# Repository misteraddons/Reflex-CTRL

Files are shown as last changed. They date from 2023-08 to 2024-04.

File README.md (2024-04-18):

# General
A series of drop in replacement circuit boards to convert console controllers directly to USB. Reflex CTRL uses [GP2040-CE](https://gp2040-ce.info/#/) firmware, and boasts an incredibly low 0.8ms latency.

## Controllers

### Config
`Web Config` mode = Start + Plug in USB, then visit [192.168.7.1](192.168.7.1)

### CTRL NES
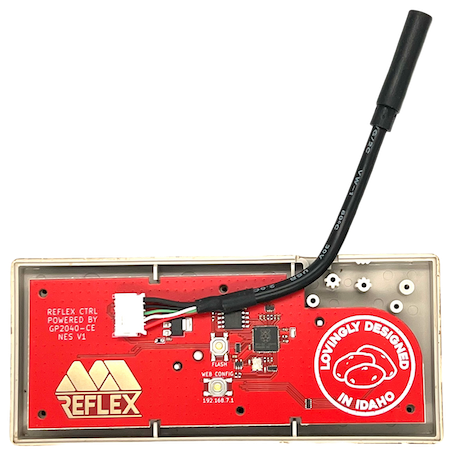
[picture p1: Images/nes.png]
CTRL NES


Update Firmware: Select + Start + Up + Plug in USB
| Mode | Button Combo |
| --- | --- |
| Nintendo Switch Mode | B + Plug in USB |
| Xinput | A + Plug in USB |

| Shortcut | Button Combo |
| --- | --- |
| D-pad mode | Select + Start + Down |
| Left analog stick mode | Select + Start + Left |
| Right analog stick mode | Select + Start + Right |
| Home | Select + Start + Up |

### CTRL SNES
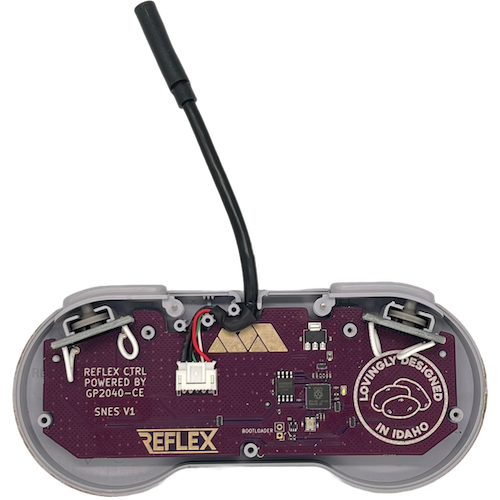
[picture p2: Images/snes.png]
CTRL SNES


Update Firmware: Select + Start + Up + Plug in USB
| Mode | Button Combo |
| --- | --- |
| Nintendo Switch Mode | B + Plug in USB |
| Xinput | A + Plug in USB |
| DirectInput / PS3 | Y + Plug in USB |
| PS4 | X + Plug in USB* |
* PS4 mode requires additional steps. Enter `Web Config` mode, then go to `Settings` >  `Input Mode Settings` > `PS4` > `Authentication Mode Settings` for more info.

| Shortcut | Button Combo |
| --- | --- |
| D-pad mode | Select + Start + Down |
| Left analog stick mode | Select + Start + Left |
| Right analog stick mode | Select + Start + Right |
| Home | Select + Start + Up |
| Turbo enable/disable | Left + Select + Button |
| Turbo rate increase | Left + Up + Select |
| Turbo rate decrease | Left + Down + Select |

### CTRL Virtual Boy
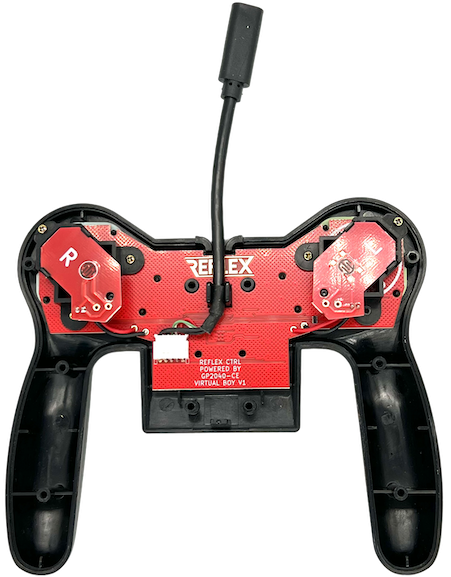
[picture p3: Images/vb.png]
CTRL Virtual Boy


Update Firmware: Select + Start + Up + Plug in USB
| Mode | Button Combo |
| --- | --- |
| Nintendo Switch Mode | Right DPad Down + Plug in USB |
| Xinput | Right DPad Right + Plug in USB |
| DirectInput / PS3 | Right DPad Left + Plug in USB |
| PS4 | Right DPad Up + Plug in USB* |
| Keyboard | R + Plug in USB* |
* PS4 mode requires additional steps. Enter `Web Config` mode, then go to `Settings` >  `Input Mode Settings` > `PS4` > `Authentication Mode Settings` for more info.

| Shortcut | Button Combo |
| --- | --- |
| D-pad mode | Select + Start + Down |
| Left analog stick mode | Select + Start + Left |
| Right analog stick mode | Select + Start + Right |
| Home | Select + Start + Up |

### CTRL Genesis 6
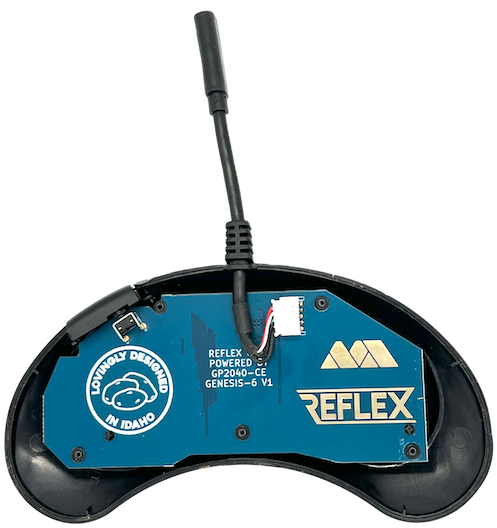
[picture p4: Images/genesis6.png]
CTRL Genesis 6


Update Firmware: Mode + Start + Up + Plug in USB
| Mode | Button Combo |
| --- | --- |
| Nintendo Switch Mode | A + Plug in USB |
| Xinput | B + Plug in USB |
| DirectInput / PS3 | X + Plug in USB |
| PS4 | Y + Plug in USB* |
* PS4 mode requires additional steps. Enter `Web Config` mode, then go to `Settings` >  `Input Mode Settings` > `PS4` > `Authentication Mode Settings` for more info.

| Shortcut | Button Combo |
| --- | --- |
| D-pad mode | Mode + Start + Down |
| Left analog stick mode | Mode + Start + Left |
| Right analog stick mode | Mode + Start + Right |
| Home | Mode + Start + Up |

### CTRL Saturn
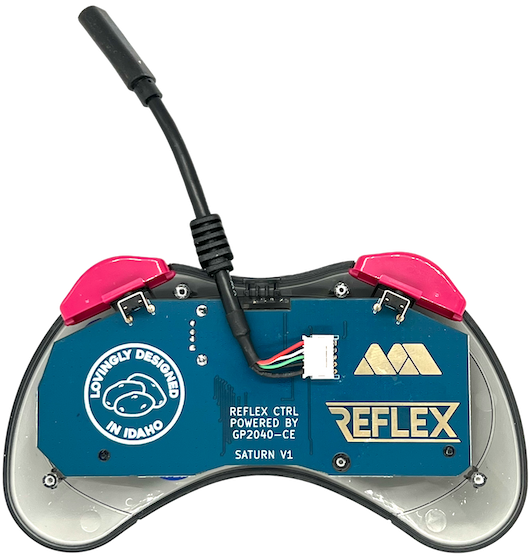
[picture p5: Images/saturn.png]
CTRL Saturn


Update Firmware: Start + Plug in USB to enter `Web Config`. Navigate to 192.168.7.1. Click `Reboot`, then `USB (BOOT SEL)`.
| Mode | Button Combo |
| --- | --- |
| Nintendo Switch Mode | A + Plug in USB |
| Xinput | B + Plug in USB |
| DirectInput / PS3 | X + Plug in USB |
| PS5 | Y + Plug in USB (Requires authentication dongle) |
* PS4 mode requires additional steps. Enter `Web Config` mode, then go to `Settings` >  `Input Mode Settings` > `PS4` > `Authentication Mode Settings` for more info.
* Xbox authentication requires an authentication dongle (TBD)

| Shortcut | Button Combo |
| --- | --- |
| D-pad mode | L + Start + Down |
| Left analog stick mode | L + Start + Left |
| Right analog stick mode | L + Start + Right |
| Home | L + Start + Up |

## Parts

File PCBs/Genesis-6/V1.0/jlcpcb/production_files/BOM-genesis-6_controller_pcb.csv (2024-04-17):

Comment | Designator | Footprint | LCSC
Conn_01x05 | J5 | JST_PH_S5B-PH-K_1x05_P2.00mm_Horizontal | C10402
1K | R3,R5,R8 | R_0402_1005Metric | C11702
SCHOTTKY DIODE | D1 | D_0603_1608Metric | C143772
100n | C11,C12,C13,C14,C5,C6,C7,C9 | C_0402_1005Metric | C1525
10u | C1,C2 | C_0402_1005Metric | C15525
27p | C3,C4 | C_0402_1005Metric | C1557
RP2040 | U4 | RP2040-QFN-56 | C2040
LED | D2 | LED_0603_1608Metric | C2290
27 | R6,R7 | R_0402_1005Metric | C25100
10K | R4 | R_0402_1005Metric | C25744
W25Q16 | FLASH1 | RPI_SPI_Flash_Universal_W25Q16 | C2843335
TVS_RCLAMP0524P-N | U1,U2,U5,U6,U7 | UDFN-10_1.35x2.6mm_P0.5mm | C316044
SW_Push | SW13,SW5 | SW_SPST_SKQG_WithStem | C318884
Button_Pad | SW12 | SW_Tactile_SPST_Angled_PTS645Vx39-2LFS | C455127
1u | C10,C8 | C_0402_1005Metric | C52923
AMS1117-3.3 | U3 | SOT-223-3_TabPin2 | C6186
Crystal_GND24_Small | Y1 | Crystal_SMD_SeikoEpson_TSX3225-4Pin_3.2x2.5mm | C9002

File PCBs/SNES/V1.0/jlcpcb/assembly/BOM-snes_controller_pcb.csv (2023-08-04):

Comment | Designator | Footprint | LCSC
1N4148 | D1,D2,D3,D4 | D_SOD-323 | C2128
10K | R1,R2,R3,R4,R5,R6,R7 | R_0603_1608Metric | C25804
TVS_RCLAMP0524P-N | U1,U2 | UDFN-10_1.35x2.6mm_P0.5mm | C316044

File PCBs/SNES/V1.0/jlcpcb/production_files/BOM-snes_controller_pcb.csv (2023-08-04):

Comment | Designator | Footprint | LCSC
Conn_01x05 | J5 | JST_PH_S5B-PH-K_1x05_P2.00mm_Horizontal | C10402
1K | R3,R5,R8 | R_0402_1005Metric | C11702
74AHC1G32 | U8 | SOT-353_SC-70-5 | C12489
SCHOTTKY DIODE | D1 | D_0603_1608Metric | C143772
100n | C11,C12,C13,C14,C5,C6,C7,C9 | C_0402_1005Metric | C1525
10u | C1,C15,C2 | C_0402_1005Metric | C15525
27p | C3,C4 | C_0402_1005Metric | C1557
RP2040 | U4 | RP2040-QFN-56 | C2040
27 | R6,R7 | R_0402_1005Metric | C25100
10K | R10,R4,R9 | R_0402_1005Metric | C25744
TVS_RCLAMP0524P-N | U1,U2,U5,U6 | UDFN-10_1.35x2.6mm_P0.5mm | C316044
Conn_01x02 | J2 | PinHeader_1x02_P2.54mm_Vertical | C492410
LED | D2 | LED_0603_1608Metric | C5137313
1u | C10,C8 | C_0402_1005Metric | C52923
AMS1117-3.3 | U3 | SOT-223-3_TabPin2 | C6186
W25Q16 | FLASH1 | SOIC127P790X216-8N | C82317
Crystal_GND24_Small | Y1 | Crystal_SMD_SeikoEpson_TSX3225-4Pin_3.2x2.5mm | C9002
MountingHole | H5 | MountingHole_1.8mm

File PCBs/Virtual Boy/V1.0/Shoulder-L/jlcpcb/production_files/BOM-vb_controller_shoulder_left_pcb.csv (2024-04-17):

Comment | Designator | Footprint | LCSC
Conn_01x02 | J1 | JST_PH_B2B-PH-K_1x02_P2.00mm_Vertical | C7433692

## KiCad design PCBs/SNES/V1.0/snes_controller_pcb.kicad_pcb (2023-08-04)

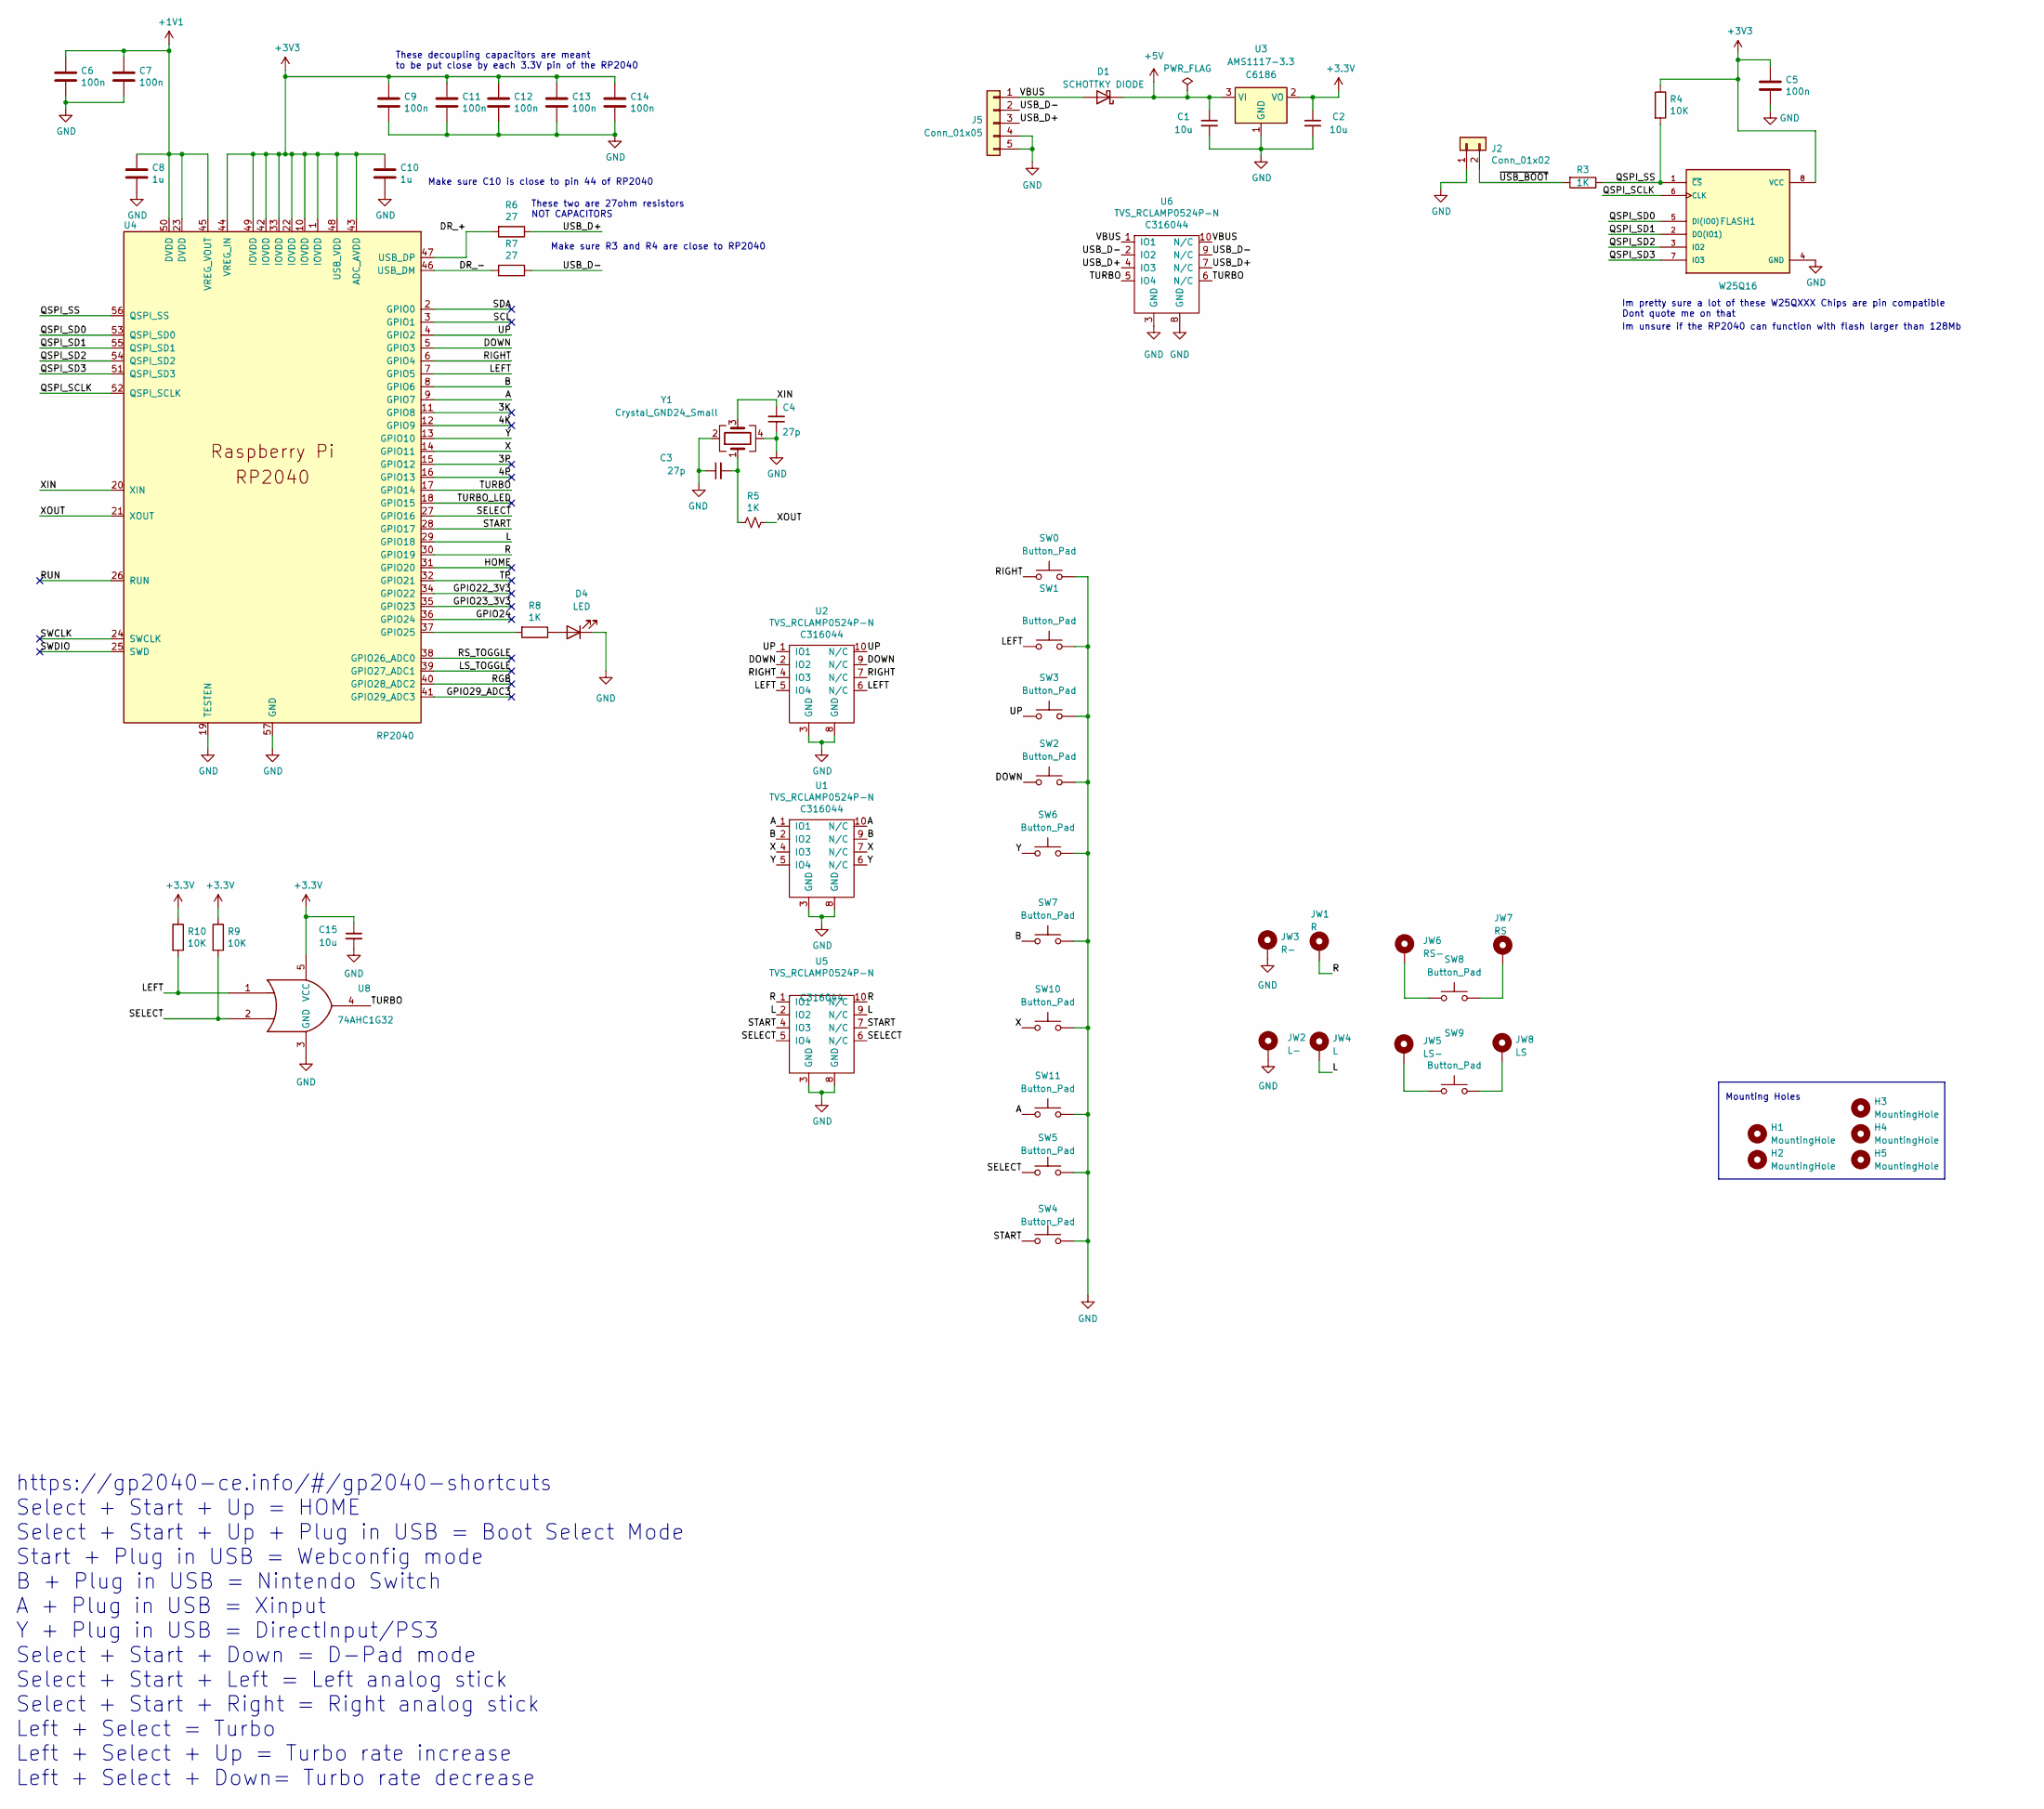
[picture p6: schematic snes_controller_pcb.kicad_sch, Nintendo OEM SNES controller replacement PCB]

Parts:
C1, C2, C15: 10u; C_0402_1005Metric; LCSC Part C15525
C3, C4: 27p; C_0402_1005Metric; LCSC Part C1557
C5, C6, C7, C9, C11, C12, C13, C14: 100n; C_0402_1005Metric; LCSC Part C1525
C8, C10: 1u; C_0402_1005Metric; LCSC Part C52923
D1: SCHOTTKY DIODE; D_0603_1608Metric; LCSC Part C143772
D4: LED; LED_0603_1608Metric; LCSC Part C5137313
FLASH1: W25Q16; SOIC127P790X216-8N; LCSC Part C82317
H1, H2: MountingHole; MountingHole_4.5mm
H3, H4: MountingHole; MountingHole_2.1mm
H5: MountingHole; MountingHole_1.8mm
J2: Conn_01x02; PinHeader_1x02_P2.54mm_Vertical; LCSC Part C492410
J5: Conn_01x05; JST_PH_S5B-PH-K_1x05_P2.00mm_Horizontal; LCSC Part C10402
JW1: R; MountingHole_1.2mm_Pad
JW2: L-; MountingHole_1.2mm_Pad
JW3: R-; MountingHole_1.2mm_Pad
JW4: L; MountingHole_1.2mm_Pad
JW5: LS-; MountingHole_1.2mm_Pad
JW6: RS-; MountingHole_1.2mm_Pad
JW7: RS; MountingHole_1.2mm_Pad
JW8: LS; MountingHole_1.2mm_Pad
R3, R5, R8: 1K; R_0402_1005Metric; LCSC Part C11702
R4, R9, R10: 10K; R_0402_1005Metric; LCSC Part C25744
R6, R7: 27; R_0402_1005Metric; LCSC Part C25100
SW0, SW1, SW2, SW3, SW4, SW5, SW8, SW9: Button_Pad; BTN_Controller_Dpad_0.3_0.3
SW6, SW7, SW10, SW11: Button_Pad; BTN_Controller_5mm_0.3_0.3
U1, U2, U5, U6: TVS_RCLAMP0524P-N; UDFN-10_1.35x2.6mm_P0.5mm; LCSC Part C316044
U3: AMS1117-3.3; SOT-223-3_TabPin2; LCSC Part C6186
U4: RP2040; RP2040-QFN-56; LCSC Part C2040
U8: 74AHC1G32; SOT-353_SC-70-5; LCSC Part C12489
Y1: Crystal_GND24_Small; Crystal_SMD_SeikoEpson_TSX3225-4Pin_3.2x2.5mm; LCSC Part C9002

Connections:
+1V1: C6.1, C7.1, C8.1, U4.23 (DVDD), U4.45 (VREG_VOUT), U4.50 (DVDD)
+5V: C1.1, D1.1 (K), U3.3 (VI)
/3K: U4.11 (GPIO8)
/3P: U4.15 (GPIO12)
/4K: U4.12 (GPIO9)
/4P: U4.16 (GPIO13)
/A: SW11.2, U1.1 (IO1), U1.10 (N/C), U4.9 (GPIO7)
/B: SW7.2, U1.2 (IO2), U1.9 (N/C), U4.8 (GPIO6); also elsewhere on the board
/DOWN: SW2.1, U2.2 (IO2), U2.9 (N/C), U4.5 (GPIO3)
/DR_+: R6.2, U4.47 (USB_DP)
/DR_-: R7.2, U4.46 (USB_DM)
/GPIO22_3V3: U4.34 (GPIO22)
/GPIO23_3V3: U4.35 (GPIO23)
/GPIO24: U4.36 (GPIO24)
/GPIO29_ADC3: U4.41 (GPIO29_ADC3)
/HOME: U4.31 (GPIO20)
/L: JW4.1, U4.29 (GPIO18), U5.2 (IO2), U5.9 (N/C)
/LEFT: R10.2, SW1.1, U2.5 (IO4), U2.6 (N/C), U4.7 (GPIO5), U8.1
/LS_TOGGLE: U4.39 (GPIO27_ADC1)
/QSPI_SCLK: FLASH1.6 (CLK), U4.52 (QSPI_SCLK)
/QSPI_SD0: FLASH1.5 (DI(IO0)), U4.53 (QSPI_SD0)
/QSPI_SD1: FLASH1.2 (DO(IO1)), U4.55 (QSPI_SD1)
/QSPI_SD2: FLASH1.3 (IO2), U4.54 (QSPI_SD2)
/QSPI_SD3: FLASH1.7 (IO3), U4.51 (QSPI_SD3)
/QSPI_SS: FLASH1.1 (~CS), R3.1, R4.2, U4.56 (QSPI_SS)
/R: JW1.1, U4.30 (GPIO19), U5.1 (IO1), U5.10 (N/C)
/RGB: U4.40 (GPIO28_ADC2)
/RIGHT: SW0.1, U2.4 (IO3), U2.7 (N/C), U4.6 (GPIO4)
/RS_TOGGLE: U4.38 (GPIO26_ADC0)
/RUN: U4.26 (RUN)
/SCL: U4.3 (GPIO1)
/SDA: U4.2 (GPIO0)
/SELECT: R9.2, SW5.2, U4.27 (GPIO16), U5.5 (IO4), U5.6 (N/C), U8.2
/START: SW4.2, U4.28 (GPIO17), U5.4 (IO3), U5.7 (N/C)
/SWCLK: U4.24 (SWCLK)
/SWDIO: U4.25 (SWD)
/TP: U4.32 (GPIO21)
/TURBO: U4.17 (GPIO14), U6.5 (IO4), U6.6 (N/C), U8.4
/TURBO_LED: U4.18 (GPIO15)
/UP: SW3.1, U2.1 (IO1), U2.10 (N/C), U4.4 (GPIO2)
/USB_D+: J5.3, R6.1, U6.4 (IO3), U6.7 (N/C)
/USB_D-: J5.2, R7.1, U6.2 (IO2), U6.9 (N/C)
/VBUS: D1.2 (A), J5.1, U6.1 (IO1), U6.10 (N/C)
/X: SW10.2, U1.4 (IO3), U1.7 (N/C), U4.14 (GPIO11)
/XIN: C4.2, U4.20 (XIN), Y1.3
/XOUT: R5.1, U4.21 (XOUT)
/Y: SW6.2, U1.5 (IO4), U1.6 (N/C), U4.13 (GPIO10)
/~USB_BOOT: J2.2, R3.2
GND: C1.2, C2.2, C3.1, C4.1, C5.2, C6.2, C7.2, C8.2, C9.2, C10.2, C11.2, C12.2, C13.2, C14.2, C15.2, FLASH1.4 (GND), J2.1, J5.4, J5.5, JW2.1, JW3.1, SW0.2, SW1.2, SW2.2, SW3.2, SW4.1, SW5.1, SW6.1, SW7.1, SW10.1, SW11.1, U1.3 (GND), U1.8 (GND), U2.3 (GND), U2.8 (GND), U3.1 (GND), U4.19 (TESTEN), U4.57 (GND), U5.3 (GND), U5.8 (GND), U6.3 (GND), U6.8 (GND), U8.3 (GND), Y1.2, Y1.4; also elsewhere on the board
unnamed: C3.2, R5.2, Y1.1
unnamed 50: R8.1; also elsewhere on the board
unnamed: JW5.1, SW9.1
unnamed: JW6.1, SW8.1
unnamed: JW7.1, SW8.2
unnamed: JW8.1, SW9.2
unnamed: R8.2, U4.37 (GPIO25)

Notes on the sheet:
https://gp2040-ce.info/#/gp2040-shortcuts Select + Start + Up = HOME Select + Start + Up + Plug in USB = Boot Select Mode Start + Plug in USB = Webconfig mode B + Plug in USB = Nintendo Switch A + Plug in USB = Xinput Y + Plug in USB = DirectInput/PS3 Select + Start + Down = D-Pad mode Select + Sta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
Mounting Holes
These two are 27ohm resistors NOT CAPACITORS
Make sure R3 and R4 are close to RP2040
Im pretty sure a lot of these W25QXXX Chips are pin compatible Dont quote me on that
Im unsure if the RP2040 can function with flash larger than 128Mb
These decoupling capacitors are meant to be put close by each 3.3V pin of the RP2040
Make sure C10 is close to pin 44 of RP2040

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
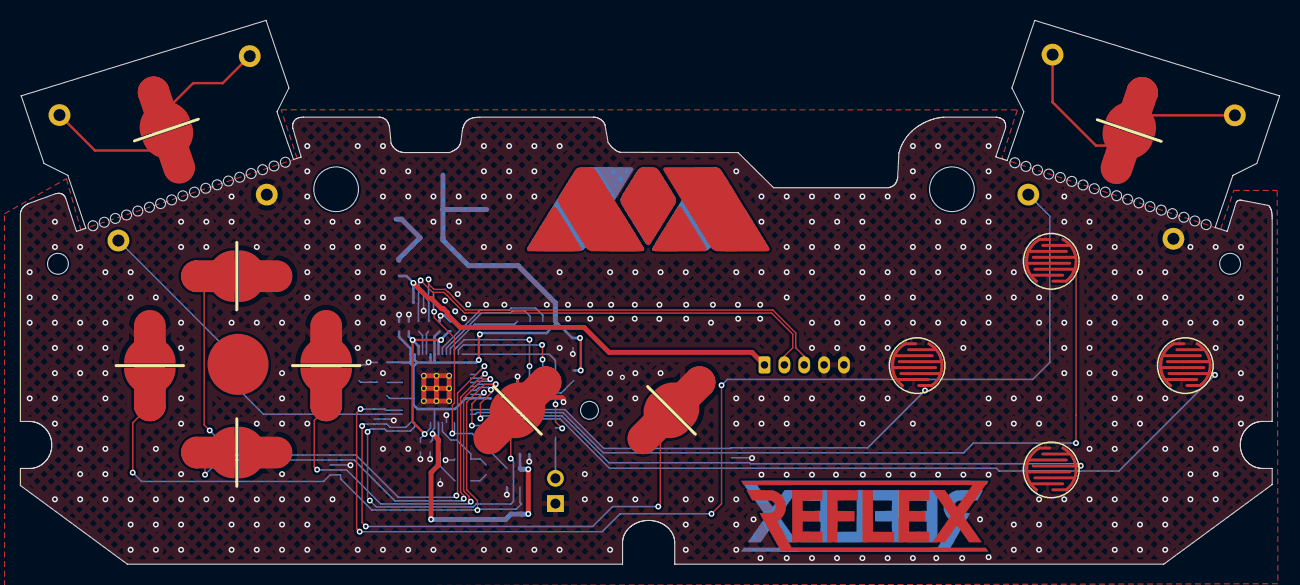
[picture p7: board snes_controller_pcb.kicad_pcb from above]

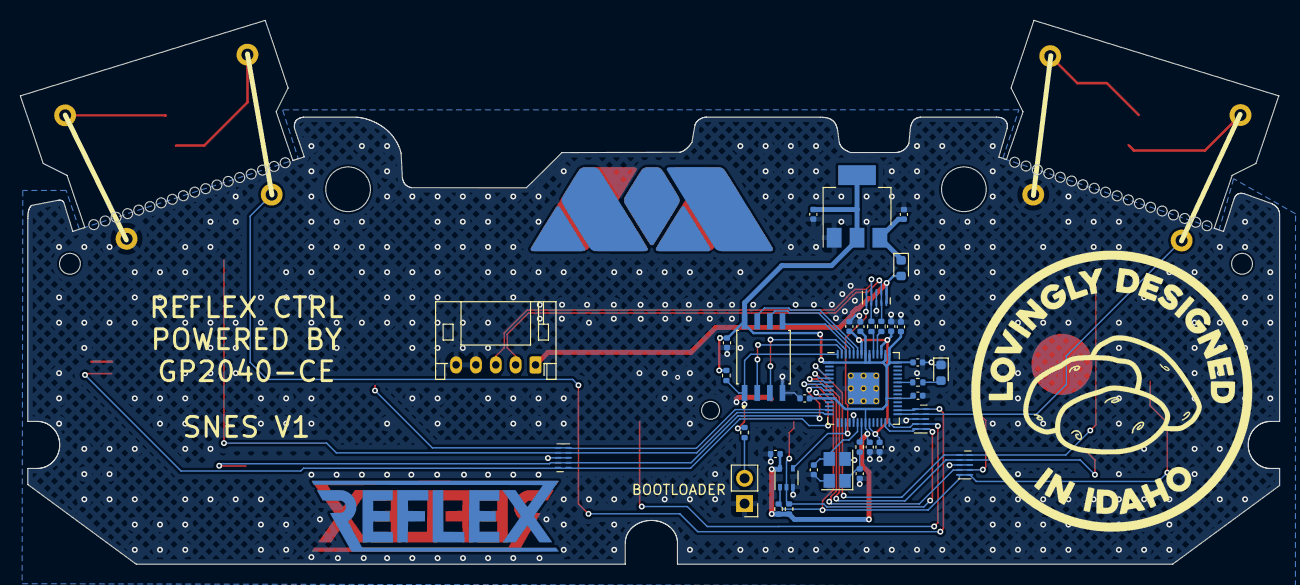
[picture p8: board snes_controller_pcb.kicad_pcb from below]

Board: 2 copper layers, 126.8 x 54.7 mm, 67 parts (39 on the bottom side), 38 nets.

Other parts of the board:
D2: LED; LED_0603_1608Metric
Ref**: Val**; MiSTer_Addons_MA_25mm
Ref**#2, Ref**#6: Val**; Reflex_Copper_30mm
Ref**#3: Val**; Controller_SNES_OEM
Ref**#4: Val**; Idaho_XL
Ref**#5: Val**; MiSTer_Addons_MA_25mm
locked: Button_Pad; BTN_Controller_5mm_0.3_0.3

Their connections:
/B: locked.2; also elsewhere on the board
GND: D2.1 (K), locked.1; also elsewhere on the board
unnamed 50: D2.2 (A); also elsewhere on the board

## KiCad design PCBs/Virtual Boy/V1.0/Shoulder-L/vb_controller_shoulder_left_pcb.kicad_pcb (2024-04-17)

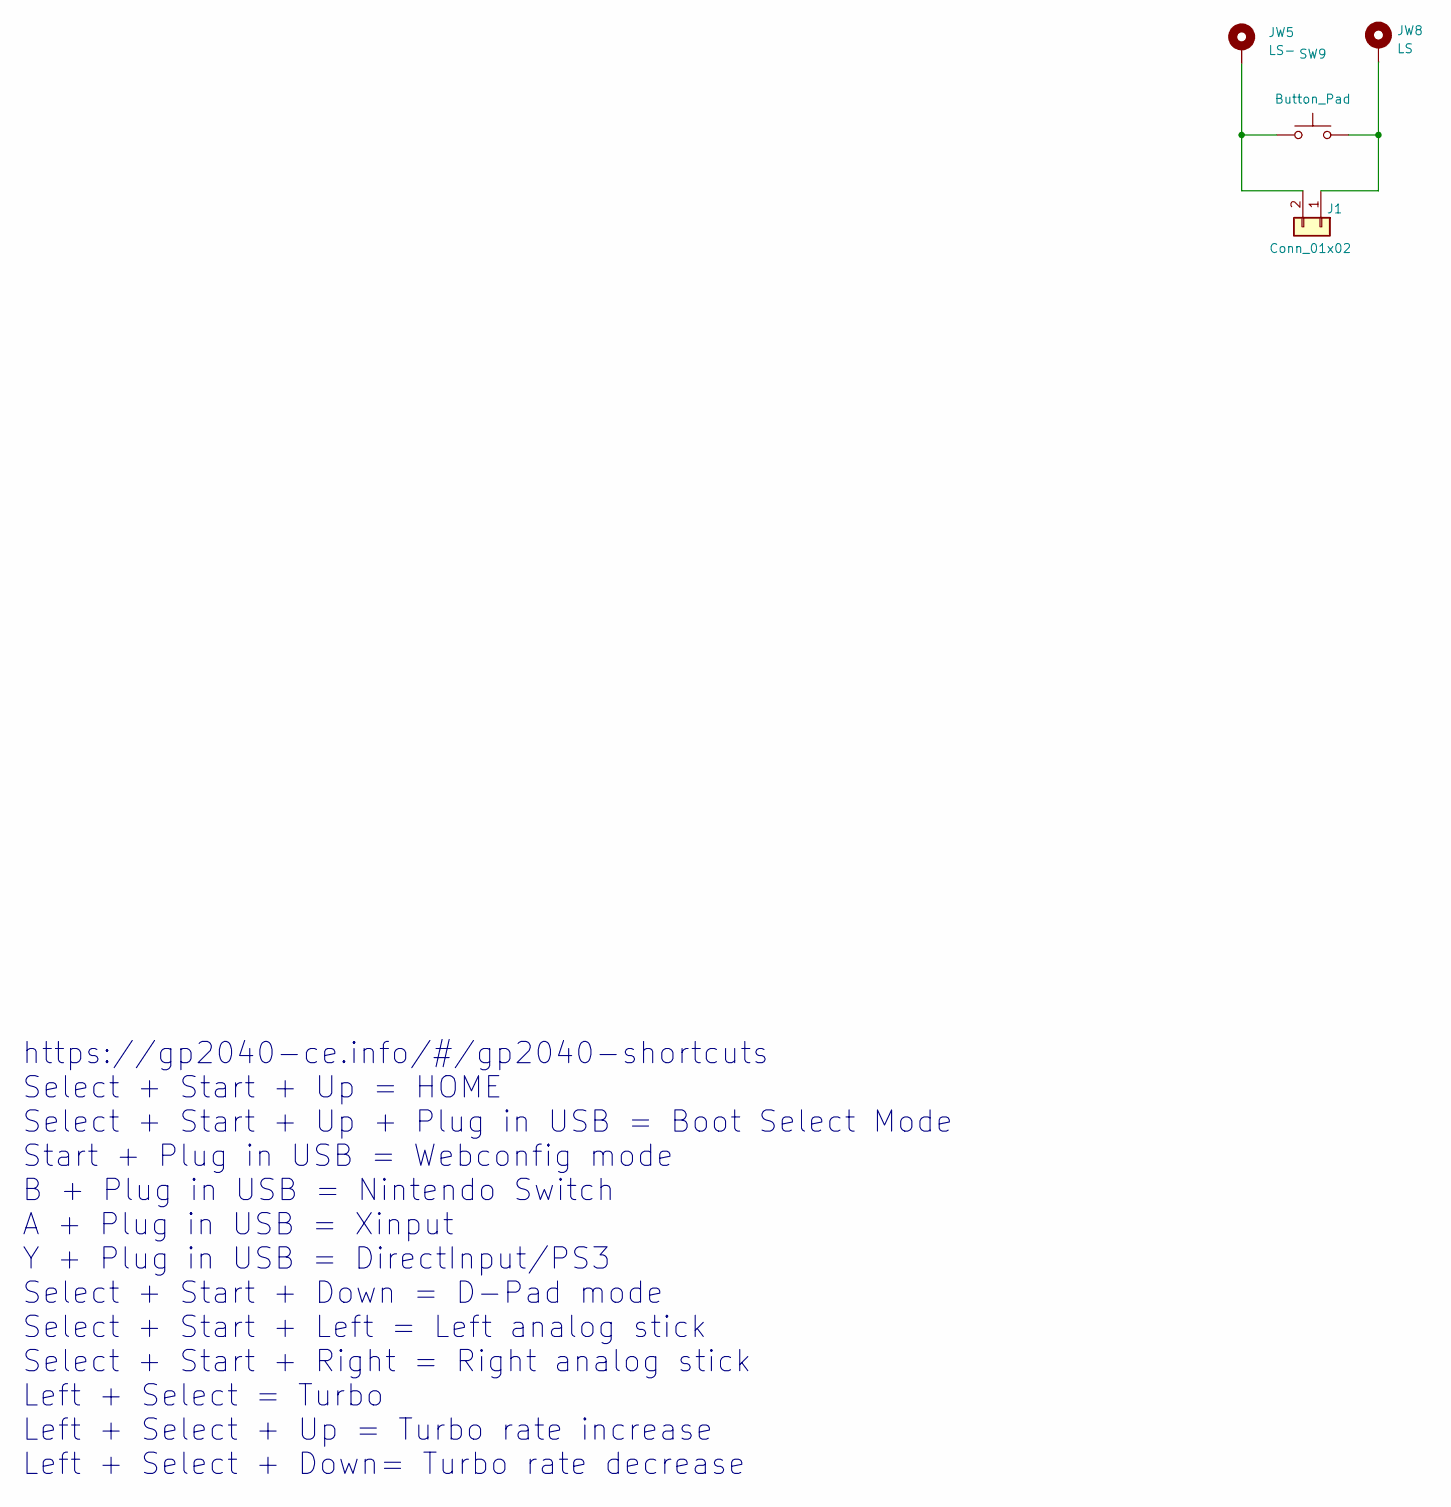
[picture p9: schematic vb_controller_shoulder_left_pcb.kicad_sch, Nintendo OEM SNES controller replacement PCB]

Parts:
J1: Conn_01x02; JST_PH_B2B-PH-K_1x02_P2.00mm_Vertical; LCSC Part C7433692
JW5: LS-; MountingHole_1.2mm_Pad
JW8: LS; MountingHole_1.2mm_Pad
SW9: Button_Pad; BTN_Controller_5mm_0.3_0.3

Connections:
unnamed: J1.1, JW8.1, SW9.2
unnamed: J1.2, JW5.1, SW9.1

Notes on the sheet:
https://gp2040-ce.info/#/gp2040-shortcuts Select + Start + Up = HOME Select + Start + Up + Plug in USB = Boot Select Mode Start + Plug in USB = Webconfig mode B + Plug in USB = Nintendo Switch A + Plug in USB = Xinput Y + Plug in USB = DirectInput/PS3 Select + Start + Down = D-Pad mode Select + Sta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

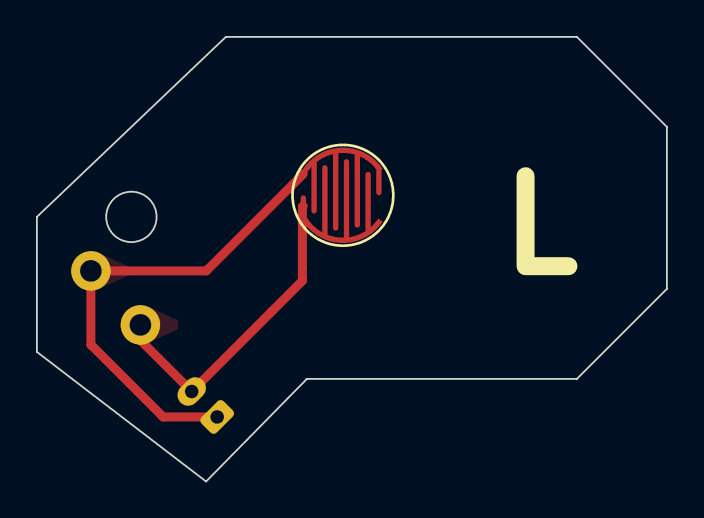
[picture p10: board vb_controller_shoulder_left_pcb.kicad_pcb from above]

Board: 2 copper layers, 35.0 x 24.7 mm, 4 parts (1 on the bottom side), 2 nets.

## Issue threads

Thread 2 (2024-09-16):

Please add Test Points for some extra GPIO

Helder1981, 2024-09-16:
It would be great if some of the GPIO not used was broken out to some Test pads so we can add our own buttons as needed for example there is no way to use macros without a dedicated Macro GPIO set as the firmware does not allow a Macro button that is assigned to a button to be used. Just some test pads with a few GND test points as well on the back should suffice.

Thanks

misteraddons, 2024-09-17:
Hey, thanks for the suggestion! Given that SNES pads don’t have extra
buttons to serve as Macro, how would this work in practice?

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

Helder1981, 2024-09-17:
I would use some long stemmed tactile button and solder 2 wires to the test pads gpio & gnd and hot glue it to the back of the pcb and drill a hole on the back of the shell for the button to pop out. I kind of did this on the Saturn PCB. I broke out some GPIO and the Turbo GPIO to 2 tactiles, just waiting on the boards to be finished and shipped to me to test out.

But having some broken out as I mentioned would really help in adding some extra functionality as an option for people who want to go that route.

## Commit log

2023-08-04 SNES CTRL
    [BOM-snes_controller_pcb.csv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]
2024-04-17 Update images, add KiCad source files
    [BOM-genesis-6_controller_pcb.csv, BOM-nes_controller_pcb.csv, BOM-saturn_controller_pcb.csv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]

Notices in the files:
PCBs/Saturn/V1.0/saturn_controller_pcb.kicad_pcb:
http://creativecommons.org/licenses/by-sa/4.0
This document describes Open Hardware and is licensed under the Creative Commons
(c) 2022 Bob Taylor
